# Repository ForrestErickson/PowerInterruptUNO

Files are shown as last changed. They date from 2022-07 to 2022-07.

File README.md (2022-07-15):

# PowerInterruptUNO
## A power interrupt test device biased on UNO shield.  
For some time I have wished for a test system to interupt power, make power drop outs, of programable length to stress test micro controller based systems against unreliable reset in the cases of power interupt. I had ideas for years and finaly put something on my white board back during the early days of COVID when I was in my lab doing long over due continuing education and haunting the FaceBook groups for Arduino and ESP. I was struck how many persons were having trouble with systems not staring reliably and noticed that many micro controller development boards did not have a diode to discharge the /Reset line on a power drop out.

So I present, A shield which will switch or interrupt power to a DUT. The power comes in on a 2.1mm barrel jack and goes out on screw terminals, USB Type A connector and USB type C and on an RJ12.

The white board schematic that started it ?last year or earlier?.
KiCad 6 schematic started 20220714 about 2:00 PM EDT.

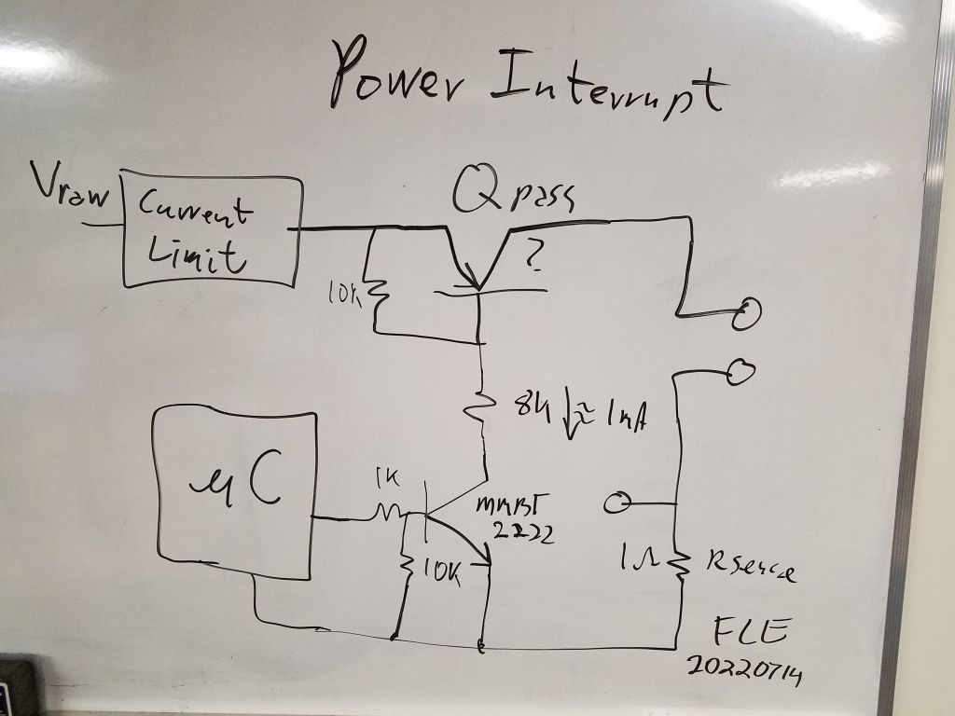
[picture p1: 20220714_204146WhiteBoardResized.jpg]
image of white board


The schematic
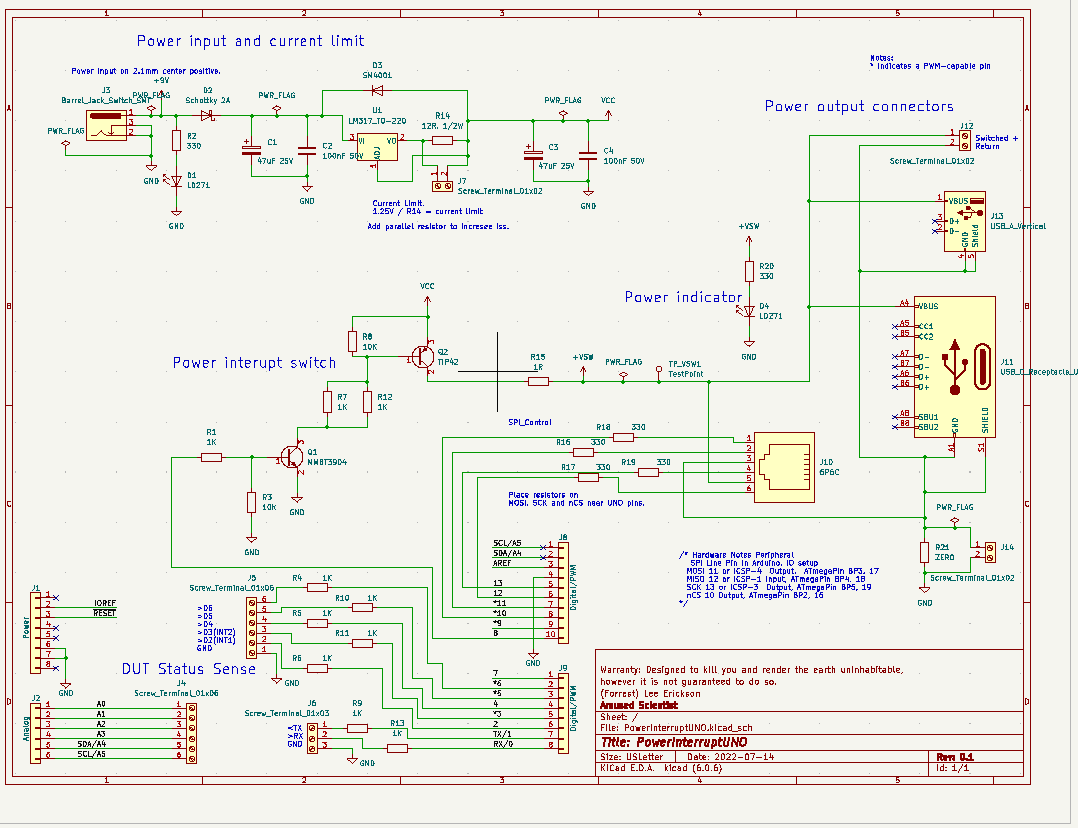
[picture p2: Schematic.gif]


The component palcement
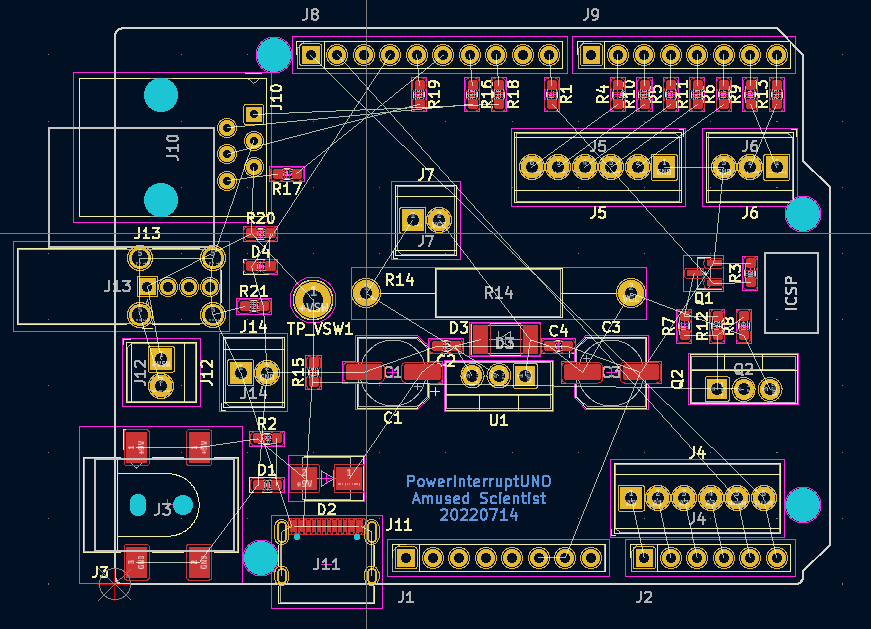
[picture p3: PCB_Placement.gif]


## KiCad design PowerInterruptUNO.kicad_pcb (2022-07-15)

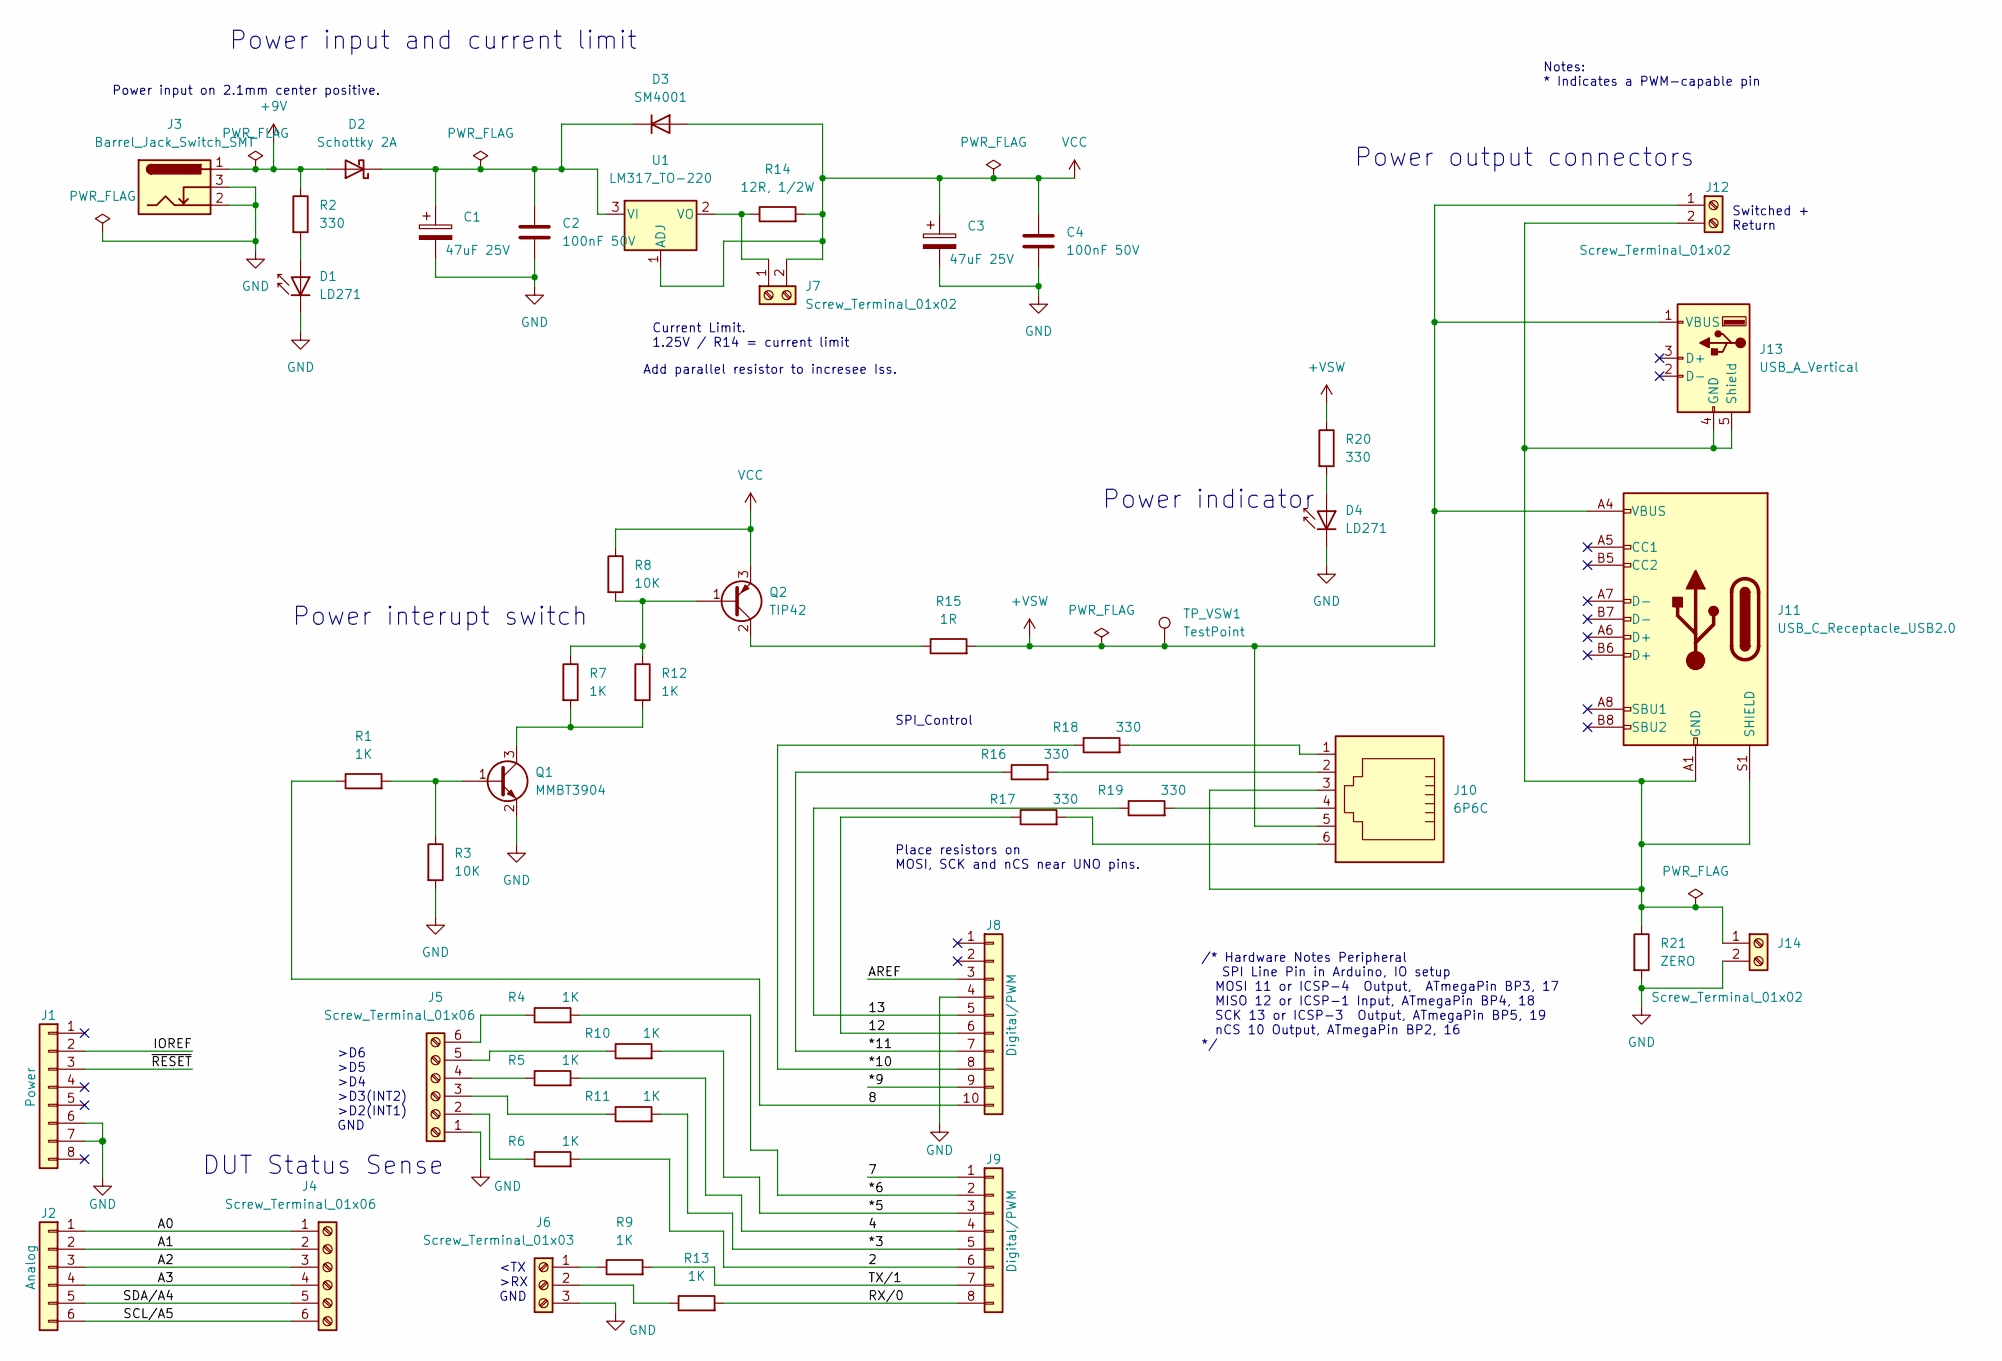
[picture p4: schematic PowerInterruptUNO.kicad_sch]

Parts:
C1, C3: 47uF 25V; CP_Elec_6.3x5.3; MPN RVT1E470M0605
C2, C4: 100nF 50V; C_0603_1608Metric_Pad1.08x0.95mm_HandSolder; MPN CC0603KRX7R9BB104
D1, D4: LD271; LED_0603_1608Metric_Pad1.05x0.95mm_HandSolder; MPN KT-0603R
D2: Schottky 2A; D_SMB; MPN SS210
D3: SM4001; D_MELF; MPN SM4001PL-TP
J1: Power; PinSocket_1x08_P2.54mm_Vertical; MPN foo
J2: Analog; PinSocket_1x06_P2.54mm_Vertical; MPN foo
J3: Barrel_Jack_Switch_SMT; BarrelJack_CLIFF_FC681465S_SMT_Horizontal; MPN XKB Connectivity / Tensility Internatio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
J4, J5: Screw_Terminal_01x06; TerminalBlock_TE_282834-6_1x06_P2.54mm_Horizontal; MPN DB125-2.54-6P-GN
J6: Screw_Terminal_01x03; TerminalBlock_TE_282834-3_1x03_P2.54mm_Horizontal; MPN DB125-2.54-3P-GN
J7, J12, J14: Screw_Terminal_01x02; TerminalBlock_TE_282834-2_1x02_P2.54mm_Horizontal; MPN DB125-2.54-2P-GN
J8: Digital/PWM; PinSocket_1x10_P2.54mm_Vertical; MPN foo
J9: Digital/PWM; PinSocket_1x08_P2.54mm_Vertical; MPN foo
J10: 6P6C; RJ12_Amphenol_54601; MPN 5555165-1
J11: USB_C_Receptacle_USB2.0; USB_C_Receptacle_XKB_U262-16XN-4BVC11; MPN U262-161N-4BVC11
J13: USB_A_Vertical; USB_A_Wuerth_614004134726_Horizontal; MPN C26235
Q1: MMBT3904; SOT-23; MPN MMBT3904
Q2: TIP42; TO-220-3_Vertical; MPN TIP42C
R1, R4, R5, R6, R7, R9, R10, R11, R12, R13: 1K; R_0603_1608Metric_Pad0.98x0.95mm_HandSolder; MPN RC0603FR-071KL
R2, R16, R17, R18, R19, R20: 330; R_0603_1608Metric_Pad0.98x0.95mm_HandSolder; MPN RC0603FR-07330RL
R3, R8: 10K; R_0603_1608Metric_Pad0.98x0.95mm_HandSolder; MPN RC0603JR-0710KL
R14: 12R, 1/2W; R_Axial_DIN0414_L11.9mm_D4.5mm_P25.40mm_Horizontal; MPN foo
R15: 1R; R_0603_1608Metric_Pad0.98x0.95mm_HandSolder; MPN foo
R21: ZERO; R_0603_1608Metric_Pad0.98x0.95mm_HandSolder; MPN foo
TP_VSW1: TestPoint; TestPoint_Loop_D2.50mm_Drill1.85mm; MPN foo
U1: LM317_TO-220; TO-220-3_Vertical; MPN LM317KCT

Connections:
+9V: D2.2 (A), J3.1, R2.1
+VSW: J10.5, J11.A4 (VBUS), J11.A9 (VBUS), J11.B4 (VBUS), J11.B9 (VBUS), J12.1, J13.1 (VBUS), R15.2, R20.1, TP_VSW1.1
/2: J9.6, R6.2
/4: J9.4, R5.2
/7: J9.1
/8: J8.10, R1.1
/12: J8.6, R17.1
/13: J8.5, R19.1
/*3: J9.5, R11.2
/*5: J9.3, R10.2
/*6: J9.2, R4.2
/*9: J8.9
/*10: J8.8, R18.1
/*11: J8.7, R16.1
/A0: J2.1, J4.1
/A1: J2.2, J4.2
/A2: J2.3, J4.3
/A3: J2.4, J4.4
/AREF: J8.3
/IOREF: J1.2
/RX/0: J9.8, R13.2
/SCL/A5: J2.6, J4.6
/SDA/A4: J2.5, J4.5
/TX/1: J9.7, R9.2
/~RESET: J1.3
GND: C1.2, C2.2, C3.2, C4.2, D1.1 (K), D4.1 (K), J1.6, J1.7, J3.2, J3.3, J5.1, J6.3, J8.4, J14.2, Q1.2 (E), R3.2, R21.2
unnamed: C1.1, C2.1, D2.1 (K), D3.1 (K), U1.3 (VI)
unnamed: D1.2 (A), R2.2
unnamed: D4.2 (A), R20.2
unnamed: J5.2, R6.1
unnamed: J5.3, R11.1
unnamed: J5.4, R5.1
unnamed: J5.5, R10.1
unnamed: J5.6, R4.1
unnamed: J6.1, R9.1
unnamed: J6.2, R13.1
unnamed: J7.1, R14.1, U1.2 (VO)
unnamed: J10.1, R18.2
unnamed: J10.2, R16.2
unnamed: J10.3, J11.A1 (GND), J11.A12 (GND), J11.B1 (GND), J11.B12 (GND), J11.S1 (SHIELD), J12.2, J13.4 (GND), J13.5 (Shield), J14.1, R21.1
unnamed: J10.4, R19.2
unnamed: J10.6, R17.2
unnamed: Q1.1 (B), R1.2, R3.1
unnamed: Q1.3 (C), R7.2, R12.2
unnamed: Q2.1 (B), R7.1, R8.2, R12.1
unnamed: Q2.2 (C), R15.1
VCC: C3.1, C4.1, D3.2 (A), J7.2, Q2.3 (E), R8.1, R14.2, U1.1 (ADJ)

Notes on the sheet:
Power output connectors
Power input on 2.1mm center positive.
Power interupt switch
Place resistors on MOSI, SCK and nCS near UNO pins.
Power indicator
Add parallel resistor to incresee Iss.
SPI_Control
Current Limit. 1.25V / R14 = current limit
Power input and current limit
DUT Status Sense
Switched + Return
<TX >RX GND
Notes: * Indicates a PWM-capable pin
>D6 >D5 >D4 >D3(INT2) >D2(INT1) GND
/* Hardware Notes Peripheral SPI Line Pin in Arduino, IO setup MOSI 11 or ICSP-4 Output, ATmegaPin BP3, 17 MISO 12 or ICSP-1 Input, ATmegaPin BP4, 18 SCK 13 or ICSP-3 Output, ATmegaPin BP5, 19 nCS 10 Output, ATmegaPin BP2, 16 */

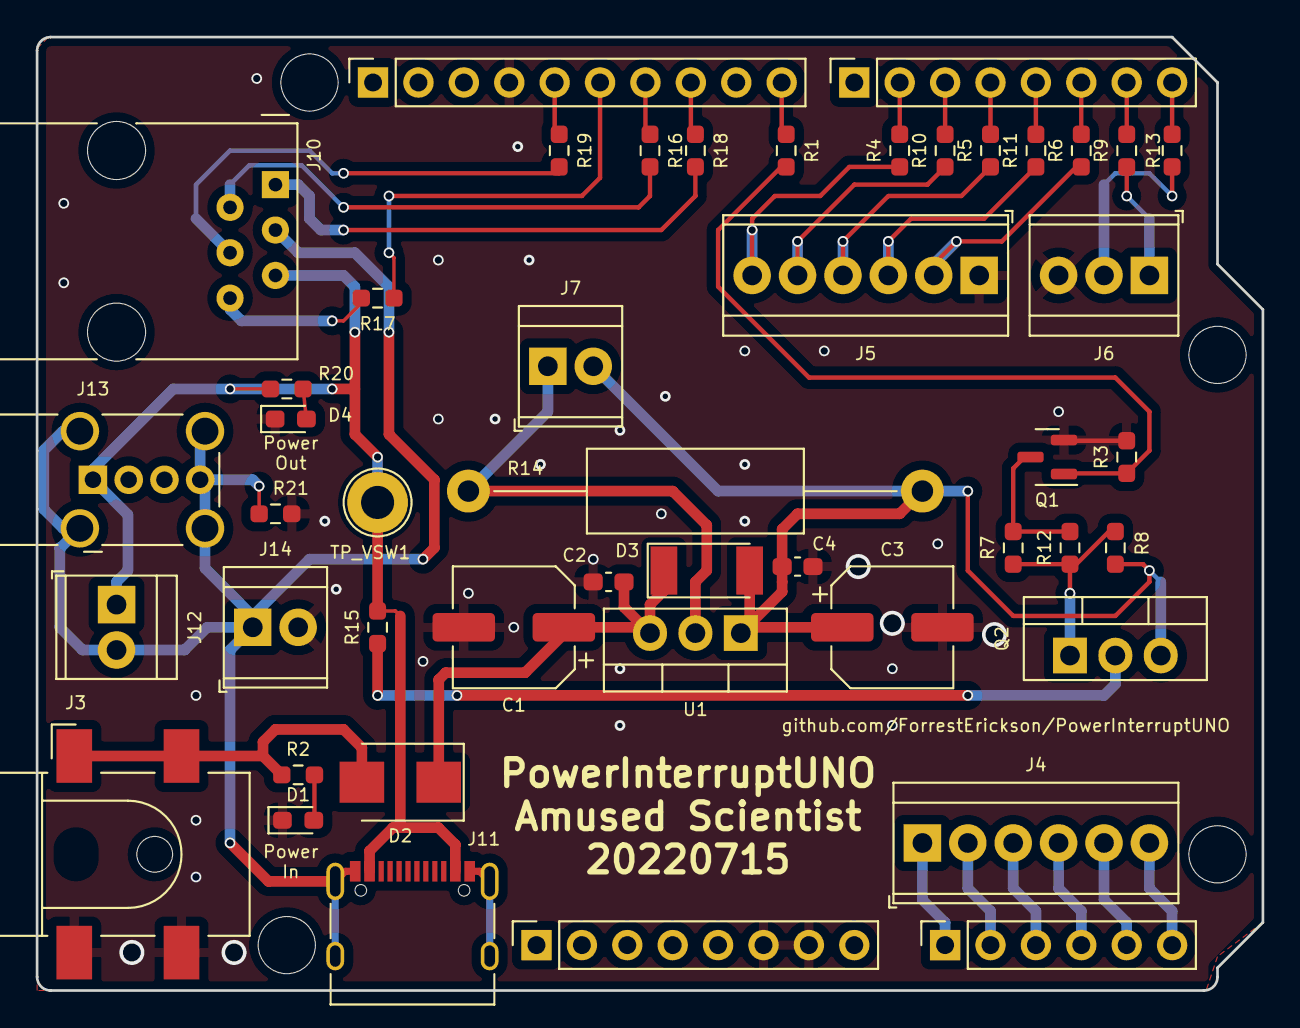
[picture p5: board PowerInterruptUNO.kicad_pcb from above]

Board: 2 copper layers, 68.6 x 53.3 mm, 51 parts (0 on the bottom side), 42 nets.

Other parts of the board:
MH1, MH2, MH3, MH4: MountingHole_3.2mm

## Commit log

2022-07-14 Initial commit of an UNO project from a template.
    [PowerInterruptUNO.kicad_pcb, PowerInterruptUNO.kicad_sch]
2022-07-14 Rough out schematic for power in. Current limit. Switched power to terminal, USBA, USBC, RJ12 SPI Controler. Inputs terminals for interupt and ADC.
    [PowerInterruptUNO.kicad_pcb, PowerInterruptUNO.kicad_sch]
2022-07-14 Annote schematic.
    [PowerInterruptUNO.kicad_sch]
2022-07-14 Clear electrical rules check on schematic.
    [PowerInterruptUNO.kicad_sch]
2022-07-14 Add JLCPCB part numberes to some components.
    [PowerInterruptUNO.kicad_sch]
2022-07-15 Place parts on PCB.
    [PowerInterruptUNO.kicad_pcb]
2022-07-15 Add photo of white board circuit.
2022-07-15 Add screen shots of Schematic and PCB with placed components.
2022-07-15 Update README.md
    Add screen shots of Schematic and PCB with placed components.'
2022-07-15 Initial routing. 100% connected but lots of DRC errors to track down.
    [PowerInterruptUNO.kicad_pcb, PowerInterruptUNO.kicad_sch]
2022-07-15 Clear some DRC errors but many remaining including Silkscreen clipping solder mask.
    [PowerInterruptUNO.kicad_pcb]
2022-07-15 Update README.md
    Resize the white board image.
2022-07-15 Prior to moving J11 inboard
    [PowerInterruptUNO.kicad_pcb]
2022-07-15 Move J11. Change text size. Move a few other parts to help with text placement. Add visa to stich ground. DRC error related to double pads on J11 I can not clear. Do not think it is a problem (he foo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
    [PowerInterruptUNO.kicad_pcb]
